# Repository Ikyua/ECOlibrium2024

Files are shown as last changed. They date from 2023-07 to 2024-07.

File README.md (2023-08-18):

# ECOlibrium Remote Sensor Module (ESP32)

This project comprises two distinct sensor modules designed to monitor environmental conditions in both indoor and outdoor settings. By leveraging various sensors, the modules provide real-time data, ensuring a comprehensive understanding of environmental parameters in both contexts. <br>
The indoor and outdoor modules share similarities in design, but differences exist in the functionality of some sensors.

## Description
### General WiFi/Web Server Functionality
Software for these modules were developed in Arduino IDE, as it is compatible with the ESP32. The modules use the WiFiManager for seamless WiFi connection management. This allows the module to automatically connect to available networks when powered on. For serving web content, ESPAsyncWebServer allows for asynchronous handling of web requests, improving the efficacy of the web interface. The data from the sensors is presented via a user-friendly HTML interface, enabling users to have clear insights into the environmental parameters being monitored.
### Sensors Used for Indoor Module
SCD40: Measures carbon dioxide concentrations, crucial for monitoring indoor air quality and ventilation efficiency.<br>
SEN55: measures particulate matter, humidity, temperature, VOCs (Volatile Organic compounds), and NOx (Nitrogen Oxide) to provide a clear picture of air quality.
### Sensors Used for Outdoor Module
PMS5003: Measures varous sizes of particulate matter. <br>
PMS7003: Measures varous sizes of particulate matter (Interchangeable with the PMS5003). <br>
BME280: Measures temperature, humidity, and barometric pressure, and altitude. <br>
SHT31: Measures temperature and humidty (Interchangeable with the BME280). <br>
SGP41: Measures VOCs and NOx, integrating with the BME280 to obtain essential temperature and humidity data for accurate algorithmic readings. <br>
Detailed explanations of the functionalities and associated libraries will be provided below.

## Getting Started
## Wiring
## Indoor Module
### SCD40

| ESP32 Pin | Sensor Pin | Description |
|:-:|:-:|:--|
| `3.3V`(BUS) | `Vcc` | The SCD40 runs off of 5 and 3.3 volts, but we chose to use 3.3V |
| `GND`(BUS)| `GND` | Ground |
| `IO22` |  `SCL` | I2C clock line |
| `IO21`| `SDA` | I2C data line |
### SEN55
| ESP32 Pin | Sensor Pin | Description |
|:-:|:-:|:--|
| `5V`(BUS) | `Vcc` | The SEN55 runs off of 5V |
| `GND`(BUS)| `GND` | Ground |
| `IO22` |  `SCL` | I2C clock line |
| `IO21`| `SDA` | I2C data line |

Refer to datasheets for pin numbers and their respective assignments if it is not specified
## Outdoor Module 

### PMS7003
| ESP32 Pin | Sensor Pin | Description |
|:-:|:-:|:--|
| `5V`(BUS) | `Vcc` | The PMS5003 runs off of 5V. |
| `GND`(BUS)| `GND` | Ground |
| `IO22` |  `SCL` | I2C clock line |
| `IO21`| `SDA` | I2C data line |
### BME280/SGP41
| ESP32 Pin | Sensor Pin | Description |
|:-:|:-:|:--|
| `3v3`(BUS) | `Vcc` | The BME280 runs off of 3.3V. |
| `GND`(BUS)| `GND` | Ground |
| `IO22` |  `SCL` | I2C clock line |
| `IO21`| `SDA` | I2C data line |
| `DNC`| `SDO` | Ignore, Do not connect |
| `DNC`| `CSB` | Ignore, Do not connect |

### Dependencies

We developed the Sensor module in Arduino IDE version 1.8.19, since this version accommodated all of our libraries<br>
# Connecting ESP32 to Arduino IDE

Setting up the ESP32 with the Arduino IDE requires a few steps. This guide will walk you through the process.

## 1. Installing the Arduino IDE

Before you can program the ESP32, you need to install the Arduino IDE.

- Download the Arduino IDE from the [official Arduino website](https://www.arduino.cc/en/Main/Software).

## 2. Setting up the ESP32 Board Support

The Arduino IDE doesn't come with support for the ESP32 by default. You have to add it manually.

### Add the ESP32 Board URL to Arduino IDE

- Open Arduino IDE.
- Go to `File` > `Preferences`.
- In the "Additional Boards Manager URLs" field, enter the following URL:
  `https://dl.espressif.com/dl/package_esp32_index.json`
- Click OK.

### Install ESP32 Board Support

- Go to `Tools` > `Board` > `Boards Manager`.
- In the search bar, type "ESP32".
- Look for "esp32 by Espressif Systems" and click on the Install button.

### Select the ESP32 Dev Module

- After installation, go to `Tools` > `Board`.
- From the list, select `ESP32 Dev Module`.

## 3. Installing Sensirion Drivers (if needed)

If your computer doesn't recognize the ESP32, you might need drivers for the USB-to-Serial chip on the board.

For the ESP32, the common chip is the CP210x from Silicon Labs.

- [Download the drivers](https://www.silabs.com/products/development-tools/software/usb-to-uart-bridge-vcp-drivers) from the Silicon Labs website.

## 4. Verifying the Connection

- Connect the ESP32 to your computer using a micro-USB cable.
- In the Arduino IDE, go to `Tools` > `Port` and select the COM port the ESP32 is connected to. The exact number can vary.
- You can now upload your sketches to the ESP32.

# Installing `.zip` Libraries in Arduino IDE

Some of these libraries might not be available directly via the Library Manager and need to be manually added using the `.zip` format.

## 1. Download Library

- First, download the desired library in `.zip` format onto your computer. 
  > **Note:** For both modules, the `ESPAsyncWebServer.h` library must be downloaded as a `.zip` library.

## 2. Open Arduino IDE

- Launch the Arduino IDE software on your computer.

## 3. Add the Library

- Go to the menu and navigate to: `Sketch` > `Include Library` > `Add .ZIP Library...`.
- A file dialog will open. Navigate to the location where you saved the downloaded `.zip` file.
- Select the `.zip` file and click 'Open'.

## 4. Confirm the Installation

- Once the library is added, restart the Arduino IDE.
- You can verify the installation by going to: `File` > `Examples`. The new library should be listed there.

## 5. Utilize the Library in Your Projects

- When you create or edit sketches, you can include the library by selecting: `Sketch` > `Include Library` > [Your Library Name], or include at the beginning of the code in the format below

### Outdoor Module Libraries
```
#include <WiFiManager.h> 
#include <WiFi.h>
#include <ESPAsyncWebServer.h>
#include <Adafruit_Sensor.h>
#include <Adafruit_BME280.h>
#include <NOxGasIndexAlgorithm.h>
#include <SensirionI2CSgp41.h>
#include <VOCGasIndexAlgorithm.h>
#include <Wire.h>
#include <time.h>
#include "PMS.h"
```
### Indoor Module Libraries
```
#include <WiFiManager.h> 
#include <WiFi.h>
#include <ESPAsyncWebServer.h>
#include <SensirionI2CSen5x.h>
#include <SensirionI2CScd4x.h>
#include <Wire.h>
#include <time.h>
```

* Describe any prerequisites, libraries, OS version, etc., needed before installing program.
* ex. Windows 10

### Installing

* How/where to download your program
* Any modifications needed to be made to files/folders

### Executing program

* How to run the program
* Step-by-step bullets
```
code blocks for commands
```

## Help

Any advise for common problems or issues.
```
command to run if program contains helper info
```

## Authors

Contributors names and contact info

Arav Sharma <br>
Isaac Amar <br>
Manhim Liu <br>
Jonas Margono

## Version History

* 0.2
    * Various bug fixes and optimizations
    * See [commit change]() or See [release history]()
* 0.1
    * Initial Release

## License

This project is licensed under the [NAME HERE] License - see the LICENSE.md file for details

## Acknowledgments

Inspiration, code snippets, etc.

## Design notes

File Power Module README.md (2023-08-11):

# Sensor Power Module README

Welcome to the Sensor Power Module repository! This README provides an overview of the components, features, and usage instructions for the Sensor Power Module, designed to provide a constant and uninterrupted power supply to sensor modules. The module is purpose-made for both indoor and outdoor applications, offering the flexibility to use a solar panel input or swap it out for a wall-plug USB input when needed.

## Schematic Files

- `Loisaida Power Schematic.sch`: The main schematic file in a standard electronic design format (e.g., KiCad, Eagle, Altium).
- `Loisaida Power Schematic.pdf`: A PDF version of the schematic for quick viewing and printing.
- `Loisaida Power Schematic.bom`: Bill of Materials (BOM) detailing all components used in the schematic.

## Table of Contents
- [Introduction](#introduction)
- [Components](#components)
- [Features](#features)
- [Setup Instructions](#setup-instructions)
- [Usage](#usage)
- [Contributing](#contributing)
- [License](#license)

## Introduction

The Sensor Power Module is designed to ensure a reliable and constant power supply for sensor modules, making it suitable for various applications. Whether your sensor module is placed indoors or outdoors, this module has you covered. The solar panel input can be easily swapped out for a wall-plug USB input (Micro-USB) when needed. The battery backup provides a reserve of power that can last several days, ensuring uninterrupted operation even in challenging conditions.

## Components

The following components are essential for assembling the Sensor Power Module:

- 20W Solar Panel (with Micro-USB output plug)
- HW318 Buck Converter
- Battery Charger
- TPS2113A Switching ICs
- MB102 Voltage Divider
- ESP32-WROOM-32U Main Board
- Resistors and Capacitors (as needed)
- USB Breakout Boards (Micro-USB female, USB-A male) for connections

## Features

- **Solar Power Management:** The solar panel or wall-plug USB input (Micro-USB) safely powers connected devices while simultaneously charging the battery with excess power via the MB102.
- **Battery Backup:** Battery backup ensures continuous operation during low solar power or nighttime, providing several days of power reserve for uninterrupted sensor operation.
- **Pass-through Avoidance:** The TPS2113A allows for switching between solar panel input and battery input; this must not be condensed into solely solar energy charging the battery to power the components, as it adds more complexity and leads to battery degradation
- **Voltage Management:** TPS2113A switching ICs automatically select the higher voltage between solar panel and battery output, providing uninterrupted power to connected modules.
- **Voltage Divider:** The HW103 voltage divider generates 5V and 3.3V outputs for powering connected components, such as an ESP32.
- **Expandability:** USB breakout boards simplify connections to components, including the solar panel with its built-in Micro-USB output plug.

## Setup Instructions

1. **Assemble Components:** Use provided schematics and component datasheets to correctly assemble the solar panel, MB102 buck converter, battery charger, switching ICs, voltage divider, and main board.

2. **Wiring:** Follow schematics to connect components. Ensure proper insulation and short circuit protection.

3. **Testing:** Thoroughly test the module under various conditions to ensure proper functionality and safety.

## Usage

Follow these steps to set up and use the Sensor Power Module:

1. Connect the solar panel's Micro-USB output plug to the Micro-USB female breakout board.

2. Wire the Micro-USB female breakout board's VBUS and GND pins to their corresponding ports on the MB102 buck converter.

3. The MB102 buck converter charges the battery and supplies power to connected devices via a TPS2113 input pin.

4. Connect the output pins of the MB102 buck converter: One set of output pins will go to the battery's input ports via an included USB-A to Micro-USB cable that attaches to a built-in USB output. The other set of output pins will connect to the TPS2113A via the adjacent output pinholes.

5. Attach the battery output to the other TPS2113A input using the battery's USB-A male breakout board.

6. The TPS2113A will automatically select the power source with the higher voltage—either the solar panel or the battery output—for uninterrupted operation.

7. Connect the TPS2113A's output to the HW103 voltage divider.

8. Wire the voltage divider's 5V and 3.3V outputs to the appropriate pins on your ESP32.

9. Ensure that all components share a common ground to establish proper electrical reference.

## Contributing to the Project

Contributions to this project are highly encouraged! If you're interested in contributing, follow these steps:

1. Fork the repository.

2. Create a new branch for your contribution

3. Implement your changes and thoroughly test them.

4. Submit a pull request with a clear and detailed description of your changes.

## License

This project is licensed under the [MIT License](LICENSE).

---

If you have any questions, suggestions, or require further assistance, please don't hesitate to reach out. We trust that the Sensor Power Module will enhance your sensor projects by providing reliable and uninterrupted power management.

Author: Lawrence Zeng
Contact: pg@loisaidalab.org

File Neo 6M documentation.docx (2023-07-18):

Neo 6M documentation

Jonas Margono – Jonas.Margono@cooper.edu

Helpful Links:

ESP32 Documentation (https://docs.espressif.com/projects/esp-idf/en/latest/esp32/hw-reference/esp32/get-started-devkitc.html)

Neo 6m GPS Guide (https://circuitdigest.com/microcontroller-projects/interfacing-neo6m-gps-module-with-esp32)

Solution to weak antenna (https://forums.raspberrypi.com/viewtopic.php?t=308629)

Parts list:

- ESP32
- Jumper wires
- Neo 6M GPS module

ESP32 Setup:

For the sensor devilment download Arduino IDE v1.8.19. This version is compatible with some of the libraries that are used for the various sensors.

Copy the boards manager here (https://dl.espressif.com/dl/package_esp32_index.json) and paste this link into the Additional Boards Manager URLs tab in the Settings in Arduino IDE.

Go to Tools and select ESP32 Dev Module under Tools.

GPS Setup

Follow the schematic below and wire the ESP32 to the GPS module. Be careful when wiring Tx and Rx pins between the two boards. Since one pin is transmitting and the other pin is receiving make sure that Tx is connected to Rx and Rx to Tx.

Schematic below:

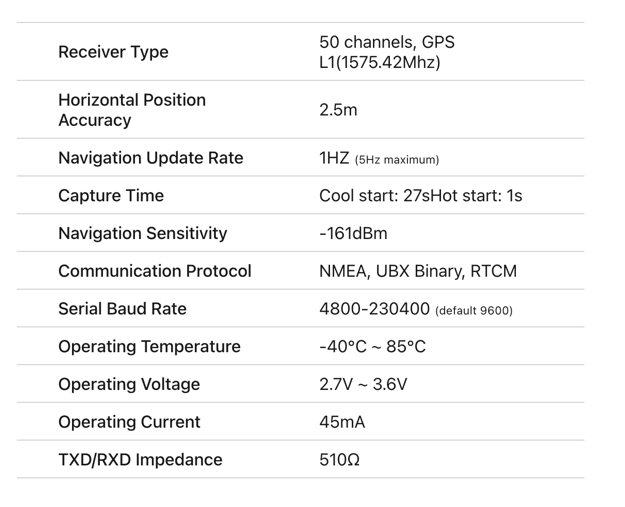
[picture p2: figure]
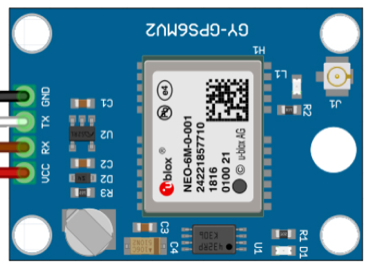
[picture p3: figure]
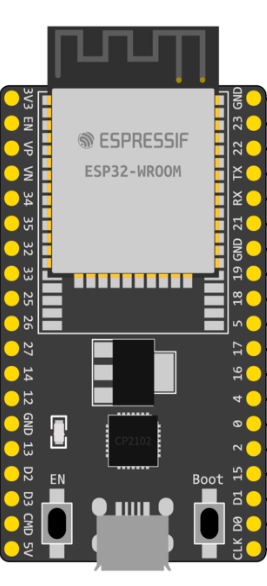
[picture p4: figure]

Specifications

*Note: Although some documentation suggests that the GPS module needs an external power supply, the 5V rail on the ESP32 is sufficient to power the GPS.

Programming:

The GPS outputs National Marine Electronics Association (NMEA) sentences. Read more here (https://circuitdigest.com/microcontroller-projects/interfacing-neo6m-gps-module-with-esp32). Fortunately, there is a library that will parse through the NMEA sentence.

Download TinyGPSPlus (https://github.com/mikalhart/TinyGPSPlus) and open the DeviceExample. Change the Baud rate in the code to 9600 (GPS module has a BAUD rate of 4800-230400).

#include <TinyGPSPlus.h>

#include <SoftwareSerial.h>

static const int RXPin = 3, TXPin = 1;

static const uint32_t GPSBaud = 9600;

// The TinyGPSPlus object

TinyGPSPlus gps;

// The serial connection to the GPS device

SoftwareSerial ss(RXPin, TXPin);

void setup()

{

Serial.begin(9600);

ss.begin(GPSBaud);

Serial.println(F("DeviceExample.ino"));

Serial.println(F("A simple demonstration of TinyGPSPlus with an attached GPS module"));

Serial.print(F("Testing TinyGPSPlus library v. ")); Serial.println(TinyGPSPlus::libraryVersion());

Serial.println(F("by Mikal Hart"));

Serial.println();

}

The highlighted sections were changed from DeviceExample.

When uploading the code make sure that the Rx and Tx connections between the GPS module and the ESP32 are not connected.

If the error “timed out for packet header” disconnect the Tx and Rx connections. Connect them back together once the code has been uploaded.

*note on Mac devices using the Arduino IDE a Python3 Path error will occur. To solve this open the terminal and make a pseudo link connection between Python and Python3. Also note that Arduino IDE 1.8.19 will have to be opened through the terminal to upload code.

Satellite Connection

Since the GPS module uses a small passive antenna cold starting the GPS will take some time.

*More info on GPS (https://www.gsmarena.com/glossary.php3?term=gps) and info on cold, warm and hot starts.

When a GPS cold starts (factory) it has no known information on the position of satellites so all the information from the satellites must be parsed from the GPS module. This can take some time.

To make a stronger connection create an aluminum foil sheet and place it underneath the antenna.

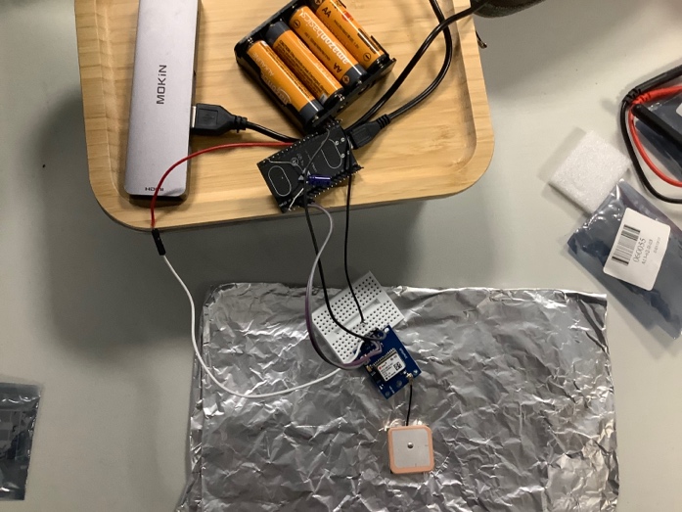
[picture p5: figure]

Aluminum foil

GPS Antenna

GPS module with antenna on aluminum foil

The foil will great a larger antenna and speed up the process. The ceramic antenna is not very strong so the GPS will not work inside. Make sure to be outside with no buildings above when trying to cold start the GPS.

Once the GPS has locked on to satellites the Antenna will no longer need the aluminum. Run the GPS normally without the aluminum.

It took about 15 minutes for the GPS to get signal so be patient when trying to get connection.

You successfully have setup a GPS. Happy Exploring!

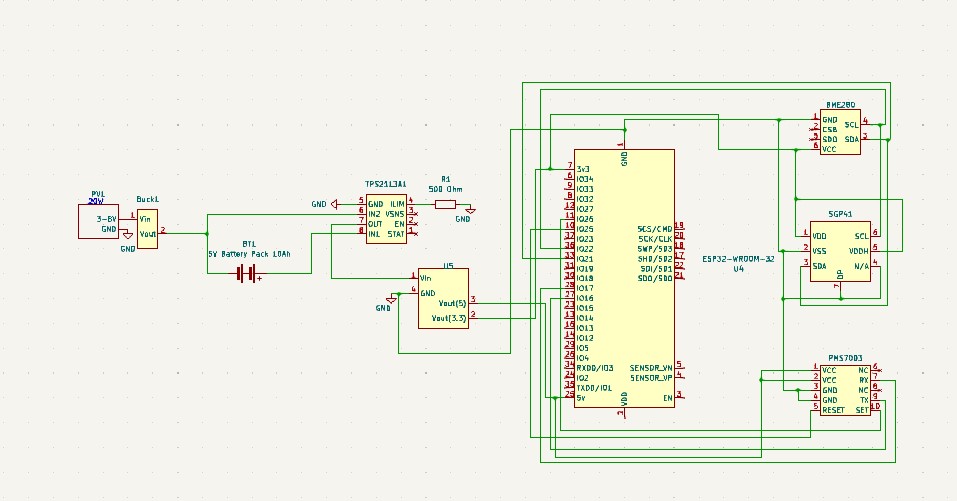
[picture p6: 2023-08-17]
outdoor module with bme280 and sgp41.jpg

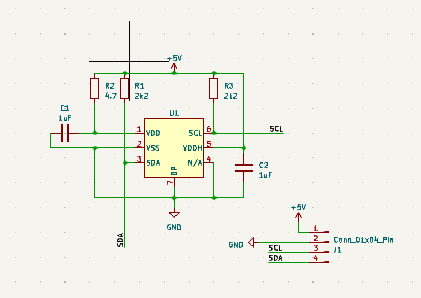
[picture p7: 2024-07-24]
SGP41.png

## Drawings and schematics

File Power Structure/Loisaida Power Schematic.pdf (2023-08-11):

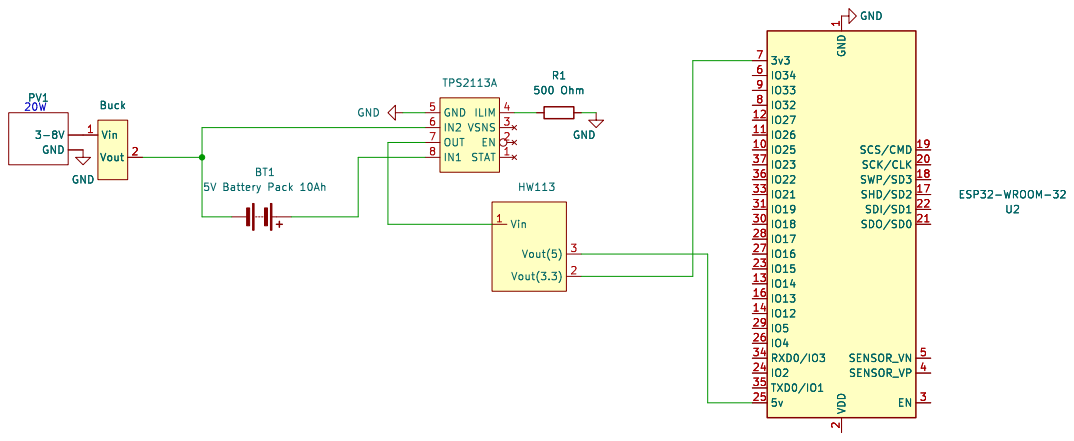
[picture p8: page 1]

2 SCK/CLK 20 SDO/SD0 21 SDI/SD1 22

Id: 1/1 Title: Lawrence Zeng Power Schematic

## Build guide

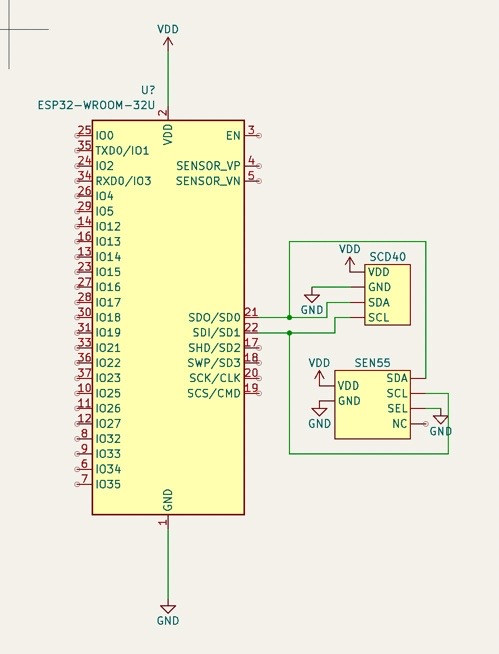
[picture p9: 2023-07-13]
wiring for scd40 and sen55.jpg

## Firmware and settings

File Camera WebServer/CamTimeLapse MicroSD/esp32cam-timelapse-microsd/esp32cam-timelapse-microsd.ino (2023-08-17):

#include <SD_MMC.h>
#include "esp_camera.h"

#define MINUTES_BETWEEN_PHOTOS 1

// Pins for ESP32-CAM

#define FLASH_PIN         4
// Camera pins
#define PWDN_GPIO_NUM     32
#define RESET_GPIO_NUM    -1
#define XCLK_GPIO_NUM      0
#define SIOD_GPIO_NUM     26
#define SIOC_GPIO_NUM     27

#define Y9_GPIO_NUM       35
#define Y8_GPIO_NUM       34
#define Y7_GPIO_NUM       39
#define Y6_GPIO_NUM       36
#define Y5_GPIO_NUM       21
#define Y4_GPIO_NUM       19
#define Y3_GPIO_NUM       18
#define Y2_GPIO_NUM        5
#define VSYNC_GPIO_NUM    25
#define HREF_GPIO_NUM     23
#define PCLK_GPIO_NUM     22

bool startMicroSD() {
  Serial.print("Starting microSD... ");

  // Pin 13 needs to be pulled-up
  // https://docs.espressif.com/projects/esp-idf/en/latest/esp32/api-reference/peripherals/sd_pullup_requirements.html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
  pinMode(13, OUTPUT);
  digitalWrite(13, HIGH);

  if(SD_MMC.begin("/sdcard", true)) {
    Serial.println("OKAY");
    return true;
  } else {
    Serial.println("FAILED");
    return false;
  }
}

bool startCamera() {
  // Turn off the flash
  pinMode(FLASH_PIN, OUTPUT);
  digitalWrite(FLASH_PIN, LOW);

  // Initialize the camera hardware
  camera_config_t config;
  config.ledc_channel = LEDC_CHANNEL_0;
  config.ledc_timer = LEDC_TIMER_0;
  config.pin_d0 = Y2_GPIO_NUM;
  config.pin_d1 = Y3_GPIO_NUM;
  config.pin_d2 = Y4_GPIO_NUM;
  config.pin_d3 = Y5_GPIO_NUM;
  config.pin_d4 = Y6_GPIO_NUM;
  config.pin_d5 = Y7_GPIO_NUM;
  config.pin_d6 = Y8_GPIO_NUM;
  config.pin_d7 = Y9_GPIO_NUM;
  config.pin_xclk = XCLK_GPIO_NUM;
  config.pin_pclk = PCLK_GPIO_NUM;
  config.pin_vsync = VSYNC_GPIO_NUM;
  config.pin_href = HREF_GPIO_NUM;
  config.pin_sscb_sda = SIOD_GPIO_NUM;
  config.pin_sscb_scl = SIOC_GPIO_NUM;
  config.pin_pwdn = PWDN_GPIO_NUM;
  config.pin_reset = RESET_GPIO_NUM;
  config.xclk_freq_hz = 20000000;
  config.pixel_format = PIXFORMAT_JPEG;
  
  // Set resolution based on whether we have extra memory
  if(psramFound()){
    Serial.println("PSRAM found. Maximum XGA resolution supported.");
    config.frame_size = FRAMESIZE_XGA;
    config.jpeg_quality = 10;
    config.fb_count = 2;
  } else {
    Serial.println("PSRAM not found. Maximum SVGA resolution supported.");
    config.frame_size = FRAMESIZE_SVGA;
    config.jpeg_quality = 12;
    config.fb_count = 1;
  }

  // Start the camera
  Serial.print("Starting camera... ");
  esp_err_t err = esp_camera_init(&config);
  if (err != ESP_OK) {
    Serial.println("FAILED");
    return false;
  } else {
    Serial.println("OKAY");
    return true;
  }
}

void takePhoto(String filename) { 
  // Take a photo and get the data

  camera_fb_t *fb = esp_camera_fb_get();
  if (!fb) {
    Serial.println("Unable to take a photo");
    return;
  }

  // Make sure it is a JPEG
  if (fb->format != PIXFORMAT_JPEG) {
     Serial.println("Capture format not JPEG");
     esp_camera_fb_return(fb); // Return the photo data
     return;
  }

  // Save the picture to the SD card

  File file = SD_MMC.open(filename.c_str(), "w");
  if(file) {
    Serial.println("Saving " + filename);
    file.write(fb->buf, fb->len);
    file.close();

    // Momentarily blink the flash
    digitalWrite(FLASH_PIN, HIGH);
    delay(100);
    digitalWrite(FLASH_PIN, LOW);
    delay(500);
  } else {
    Serial.println("Unable to write " + filename);
  }

  // Return the picture data
  esp_camera_fb_return(fb);
}

void setup() {
  // Initialize the peripherals
  Serial.begin(115200);
  while(!Serial) delay(100);

  startMicroSD();
  startCamera();

  delay(5000); // Delay 5 seconds before first photo
}

void loop() {
  // Keep a count of the number of photos we have taken
  static int number = 0;
  number++;

  // Construct a filename that looks like "/photo_0001.jpg"
  
  String filename = "/photo_";
  if(number < 1000) filename += "0";
  if(number < 100)  filename += "0";
  if(number < 10)   filename += "0";
  filename += number;
  filename += ".jpg";
  
  takePhoto(filename);

  // Delay until the next photo

  delay(MINUTES_BETWEEN_PHOTOS * 60 * 1000);
}

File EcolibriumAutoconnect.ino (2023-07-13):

//Arav Sharma
//Ecolibrium Remote Sensor
//Air Quality Monitor

#include <WiFiManager.h> 
#include <WiFi.h>
#include "ESPAsyncWebServer.h"
#include <SensirionI2CSen5x.h>
#include <SensirionI2CScd4x.h>
#include <Wire.h>
#include <time.h>
SensirionI2CSen5x sen5x;
SensirionI2CScd4x scd4x;


AsyncWebServer server(80);

float massConcentrationPm1p0;
float massConcentrationPm2p5;
float massConcentrationPm4p0;
float massConcentrationPm10p0;
float ambientHumidity;
float ambientTemperature;
float vocIndex;
float noxIndex;
uint16_t co2;

String readScdCo2() {
  
    uint16_t c;
    float t;
    float h;
    
    scd4x.readMeasurement(c, t, h);
    
    if (c != 0) {
      co2 = c;
    }
    
    return String(co2);
}

String readPm1p0() {
    
    sen5x.readMeasuredValues(
        massConcentrationPm1p0, massConcentrationPm2p5, massConcentrationPm4p0,
        massConcentrationPm10p0, ambientHumidity, ambientTemperature, vocIndex,
        noxIndex);
    
    return String(massConcentrationPm1p0);
}

String readPm2p5() {
    
    sen5x.readMeasuredValues(
        massConcentrationPm1p0, massConcentrationPm2p5, massConcentrationPm4p0,
        massConcentrationPm10p0, ambientHumidity, ambientTemperature, vocIndex,
        noxIndex);
    
    return String(massConcentrationPm2p5);
}

String readPm4p0() {
    
    sen5x.readMeasuredValues(
        massConcentrationPm1p0, massConcentrationPm2p5, massConcentrationPm4p0,
        massConcentrationPm10p0, ambientHumidity, ambientTemperature, vocIndex,
        noxIndex);
    
    return String(massConcentrationPm4p0);
}

String readPm10p0() {
    
    sen5x.readMeasuredValues(
        massConcentrationPm1p0, massConcentrationPm2p5, massConcentrationPm4p0,
        massConcentrationPm10p0, ambientHumidity, ambientTemperature, vocIndex,
        noxIndex);
    
    return String(massConcentrationPm10p0);
}

String readAmbientHumidity() {
    
    sen5x.readMeasuredValues(
        massConcentrationPm1p0, massConcentrationPm2p5, massConcentrationPm4p0,
        massConcentrationPm10p0, ambientHumidity, ambientTemperature, vocIndex,
        noxIndex);
    
    return String(ambientHumidity);
}

String readAmbientTemperature() {
    
    sen5x.readMeasuredValues(
        massConcentrationPm1p0, massConcentrationPm2p5, massConcentrationPm4p0,
        massConcentrationPm10p0, ambientHumidity, ambientTemperature, vocIndex,
        noxIndex);
    
    return String(ambientTemperature);
}

String readVocIndex() {
    
    sen5x.readMeasuredValues(
        massConcentrationPm1p0, massConcentrationPm2p5, massConcentrationPm4p0,
        massConcentrationPm10p0, ambientHumidity, ambientTemperature, vocIndex,
        noxIndex);
    
    return String(vocIndex);
}

String readNoxIndex() {
    
    sen5x.readMeasuredValues(
        massConcentrationPm1p0, massConcentrationPm2p5, massConcentrationPm4p0,
        massConcentrationPm10p0, ambientHumidity, ambientTemperature, vocIndex,
        noxIndex);
    
    return String(noxIndex);
}

const char index_html[] PROGMEM = R"rawliteral(
<!DOCTYPE HTML><html>
<head>
  <meta name="viewport" content="width=device-width, initial-scale=1">
  <script src="https://kit.fontawesome.com/d91e44f906.js" crossorigin="anonymous"></script>
  <style>
    html {
     font-family: Arial;
     display: inline-block;
     margin: 0px auto;
     text-align: center;
    }
    h2 { font-size: 3.0rem; }
    p { font-size: 3.0rem; }
    .units { font-size: 1.2rem; }
    .dht-labels{
      font-size: 1.5rem;
      vertical-align:middle;
      padding-bottom: 15px;
    }
  </style>
</head>
<body>
  <h2>ESP32 Air Quality Server</h2>
  <p>
    <i class="fas fa-smog" style="color:#000000;"></i> 
    <span class="dht-labels">PM 1.0</span>
    <span id="pm1p0">%PM1P0%</span>
    <sup class="units">ug/m3</sup>
  </p>
  <p>
    <i class="fas fa-smog" style="color:#a0a0a0;"></i>
    <span class="dht-labels">PM 2.5</span>
    <span id="pm2p5">%PM2P5%</span>
    <sup class="units">ug/m3</sup>
  </p>
  <p>
    <i class="fas fa-smog" style="color:#afafaf;"></i>
    <span class="dht-labels">PM 4.0</span>
    <span id="pm4p0">%PM4P0%</span>
    <sup class="units">ug/m3</sup>
  </p>
  <p>
    <i class="fas fa-smog" style="color:#f0f0f0;"></i> 
    <span class="dht-labels">PM 10.0</span>
    <span id="pm10p0">%PM10P0%</span>
    <sup class="units">ug/m3</sup>
  </p>
  <p>
    <i class="fas fa-project-diagram" style="color:#631fc4;"></i> 
    <span class="dht-labels">Carbon Dioxide</span>
    <span id="co2">%CO2%</span>
    <sup class="units">ppm</sup>
  </p>
  <p>
    <i class="fas fa-tint" style="color:#00add6;"></i> 
    <span class="dht-labels">Ambient Humidity</span>
    <span id="ambienthumidity">%AMBIENTHUMIDITY%</span>
    <sup class="units">&percnt;</sup>
  </p>
  <p>
    <i class="fas fa-thermometer-half" style="color:#bada55;"></i>
    <span class="dht-labels">Ambient Temperature</span>
    <span id="ambienttemperature">%AMBIENTTEMPERATURE%</span>
    <sup class="units">&deg;C</sup>
  </p>
  <p>
    <i class="fas fa-lungs" style="color:#ffb6c1;"></i> 
    <span class="dht-labels">Voc Index</span>
    <span id="vocindex">%VOCINDEX%</span>
    <sup class="units">-</sup>
  </p>
  <p>
    <i class="fas fa-grin-squint-tears" style="color:#9b870c;"></i> 
    <span class="dht-labels">Nox Index</span>
    <span id="noxindex">%NOXINDEX%</span>
    <sup class="units">-</sup>
  </p>
</body>
<script>
setInterval(function ( ) {
  var xhttp = new XMLHttpRequest();
  xhttp.onreadystatechange = function() {
    if (this.readyState == 4 && this.status == 200) {
      document.getElementById("pm1p0").innerHTML = this.responseText;
    }
  };
  xhttp.open("GET", "/pm1p0", true);
  xhttp.send();
}, 5000 ) ;

setInterval(function ( ) {
  var xhttp = new XMLHttpRequest();
  xhttp.onreadystatechange = function() {
    if (this.readyState == 4 && this.status == 200) {
      document.getElementById("pm2p5").innerHTML = this.responseText;
    }
  };
  xhttp.open("GET", "/pm2p5", true);
  xhttp.send();
}, 5000 ) ;

setInterval(function ( ) {
  var xhttp = new XMLHttpRequest();
  xhttp.onreadystatechange = function() {
    if (this.readyState == 4 && this.status == 200) {
      document.getElementById("pm4p0").innerHTML = this.responseText;
    }
  };
  xhttp.open("GET", "/pm4p0", true);
  xhttp.send();
}, 5000 ) ;

setInterval(function ( ) {
  var xhttp = new XMLHttpRequest();
  xhttp.onreadystatechange = function() {
    if (this.readyState == 4 && this.status == 200) {
      document.getElementById("pm10p0").innerHTML = this.responseText;
    }
  };
  xhttp.open("GET", "/pm10p0", true);
  xhttp.send();
}, 5000 ) ;

setInterval(function ( ) {
  var xhttp = new XMLHttpRequest();
  xhttp.onreadystatechange = function() {
    if (this.readyState == 4 && this.status == 200) {
      document.getElementById("co2").innerHTML = this.responseText;
    }
  };
  xhttp.open("GET", "/co2", true);
  xhttp.send();
}, 5000 ) ;
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

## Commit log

2023-08-02 Create SoftAPbasic.ino
    https://techtutorialsx.com/2021/01/04/esp32-soft-ap-and-station-modes/
2023-08-11 Create Power Structure
2023-08-11 Create PowerREADME
2023-08-11 Update PowerREADME
2024-07-24 Add files via upload
    LIST OF MATERIALS
    1 4.7 ohm resistor
    2 2.2k ohm resistor
    2 1uF capacitor
    1 SGP41 sensor
2024-07-24 Update Indoor_Webserver.ino
    Updated the HTML code for the indoor webserver & created a button
2024-07-24 Update Indoor_Webserver.ino
    semi-function button
2024-07-24 Update Indoor_Webserver.ino
    button to test
